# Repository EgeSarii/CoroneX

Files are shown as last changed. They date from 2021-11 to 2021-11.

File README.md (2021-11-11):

# CoroneX User Guide

This is CoroneX safety system which includes everything you wanted for your health.

<div align="center">
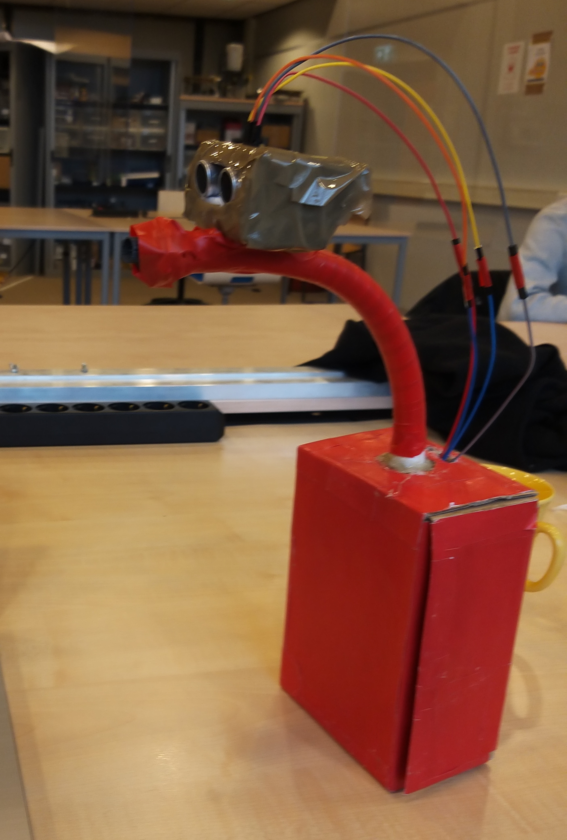
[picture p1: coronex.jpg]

<p>Our pretty CoroneX-bot/boy</p>
</div>

## Navigation Bar
* [What is this exactly?](#what-is-this-exactly)
* [Features](#features)
* [How To Initialize CoroneX](#how-to-initialize-coronex)
* [References](#references)
* [Additional Notes](#additional-notes)

## What is this exactly
> More measurement is needed against corona and it should be automatized

CoroneX is a control mechanism which is mostly designed for entrances of commonly used closed spaces.

It maintains the safety by mainly checking temperature and people counting.

In addition to that, CoroneX comes with environmental air quality, humidity and temperature sensors.

Client themselves can choose appropriate lowerbounds and upperbounds for these features. And in outside of these bounds, your security staff will get warned by e-mail system. 

A video to give you an idea about CoroneX: https://youtu.be/DwOEBgt9jCc

## Features
**on Wemos D1 Mini:**
- Wemos SHT30 Humidity and Temperature Shell: https://www.wemos.cc/en/latest/d1_mini_shield/sht30.html
- CCS811 Air Quality Sensor: https://cdn.sparkfun.com/assets/learn_tutorials/1/4/3/CCS811_Datasheet-DS000459.pdf
---
**on Arduino Uno:**
- MLX90614 Infra-red Thermometer: https://www.melexis.com/en/product/mlx90614/digital-plug-play-infrared-thermometer-to-can
- HC-SR04 Distance sensor: http://web.eece.maine.edu/~zhu/book/lab/HC-SR04%20User%20Manual.pdf
---
**on Your Device:**
- Any web camera connected or IP camera (We used Raspberry Camera Module: https://www.raspberrypi.org/documentation/usage/camera/)

## How To Initialize CoroneX
Setup your device: (For us it was Raspberry Pi 4 and preferably a LINUX distro)

- According to your device, you will probably need I2C, GPIO, SerialPort configs. Be ready for much more necessary library and configurations on your system. There was a pile of solved issues for us in 14 weeks that took our noticable effort...
- on your device download Arduino IDE

Now, we set up Arduino Uno first:
- In board manager choose, Arduino Uno configurations.
- Import necessary libraries from library manager in Arduino IDE that is related with mlx-thermometer.ino.
- Connect the cables of MLX and HC-SR04 to Uno properly.
- Connect your Uno to USB port of your device. Upload mlx-thermometer.ino to your Arduino Uno and it's done!

(Optional) Secondly, we set up WEMOS D1 Mini:
- In Arduino IDE's preferences add: https://arduino.esp8266.com/stable/package_esp8266com_index.json
- In board manager choose, WEMOS D1 Mini & R2... configurations
- Import necessary libraries from library manager in Arduino IDE that is related with HealthyRoom.ino.
- Don't forget to change variables ssid to your Wi-Fi's ssid and password to your Wi-Fi's password. Be sure that WEMOS and your device is connected to the same network.
- Connect the cables of CCS811 and SHT30 to WEMOS properly.
- Connect your WEMOS to USB port of your device. Upload HealthyRoom.ino to your WEMOS and it's done!

Now, back to our device:
- Install Python 3.7
- with pip3 install, install requirements you will find in /python_code/People-Counting-in-Real-Time-master/requirements.txt
- Run CoroneX.py via your editor or using bash:
```
	python3 CoroneX.py
```
- Enter all your credentials and submit them! It is pretty straight-forward process(YOUR PROGRAM WILL CRASH IN ILLEGAL CASES, IF YOUR CREDENTIALS ARE WRONG!)
- It will initialize the example testing video, if there are no URLs entered.
- In case of library non-existance raises, we are sorry to be not mentioned it about requirements.txt. 

## References
People tracking and counting mainly implemented by using this repository.
```
	https://github.com/saimj7/People-Counting-in-Real-Time.git
```
You can find his references in his page also in "python_code" folder that contains altered version of his project.

## Additional Notes

- Some sort of files is unnecessary for this project. We couldn't find a time to clean all of them. You can easily distinguish the relatable codes and files from unrelated ones.

[Back to navigation bar](#navigation-bar)

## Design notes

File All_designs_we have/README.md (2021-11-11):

This is the folder of the designs for our mechanical part for measurement box. It contains 3 parts. 
We have designed this and thought we can print it by 3D printer, but its going to be more than 30 hours
so we decided to cancel them. Yet we have uploaded. 
The parts contains the components of design. We have done our current design inspirend by these designs and components.

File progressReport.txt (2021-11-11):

Progress report team1-2 (Ege SARI s1034535 Alperen OZKURT s1037565)

W45 2-8 November 

We have worked on fixing DHT-22, our humidity sensor. 
We have accomplished to fix it but it is unstable so we have decided to work with a 
humidity-temperature sensor shield SHT-30 in order to make progress and SHT-30 works. 
Also we have worked about sending an e-mail to users when the temperature or 
humidity is anormal in the room space and managed it! In conclusion, we have done 
debugging and fixing and also added a new feature about sending an e-mail with related 
to humidity-temperature sensor.

W46 9-15 November

We have worked on creating a web iste for the users as a user interface, where the users
 can change the e-mail address to send or to receieve and also the users can change the 
 intervals for safe limits of temperature and humidity levels. Besides this, we have 
 created an executable file of our python program and merged it with our website so 
 when the executable file is on run, both Arduino (temperature and humidity) and 
 Python(CO2 levels and amount of volatile organic compounds) will work. We have done 
 that but since Raspberry pi 4 is a bit slow, we couldn't manage to run that. In finally, 
 we have also started to work on a cover which fits on the raspberry pi and cables so that 
 our project would look nice.

W47 16-22 November

We have finished our 3D project for cover but it didn't worked because we have designed it in milimeters. So for that we failed, we will work on that next week. Also we have improved the graphical user interface for the inputs, which looks more stylish.

W48 23-29 November

We have worked on the cover for our components and we have managed it, the last job for this is to decorate it with coloured papers or paint. Also we have nearly completed our interface for users.

W49 30 November-6 December

We have completed the interface for users and worked on debugging for some small mistakes and problems. Also we have worked on the intervals for optimal temperature values.

W50 7-13 December

We have completed most parts of the project. We have managed to connect all components together and connected it with user interfaces, warning e-mail system. Also we have attached a distance sensor in order to check if the user use thermometer in a correct way. Also we have completed a cover for the components. So we are close to the end. Next week we are planning to record a video for demonstration of our project and we will write a proper report and also we are planning to present our project.

W51 14-20 December
We have completed the project! We have also added Url section for IP cameras and also tested our project. It works as wanted. We have recorded some videos and taken some pictures. Also while I was writing this report, we are uploading the project code to here, Gitlab. 
We have completed the project in time and we are very happy about it.

W52 21-27 December

W53 28 December-3 January

W1 4-10 January

w2 11-17 January

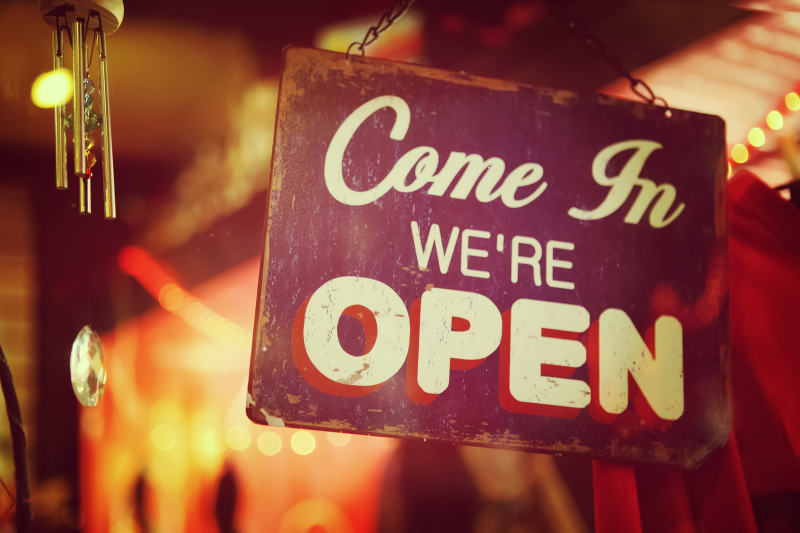
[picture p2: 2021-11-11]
python_code/People-Counting-in-Real-Time-master/download.png

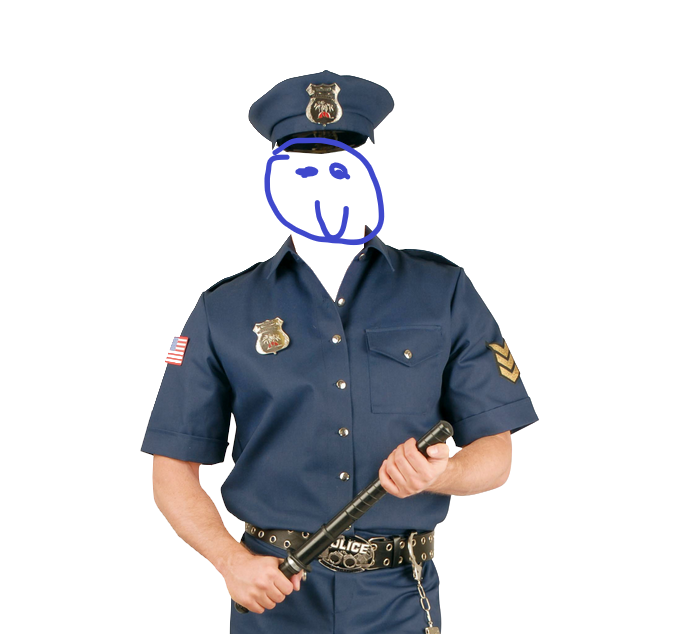
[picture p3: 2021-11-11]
python_code/People-Counting-in-Real-Time-master/REPRES.png

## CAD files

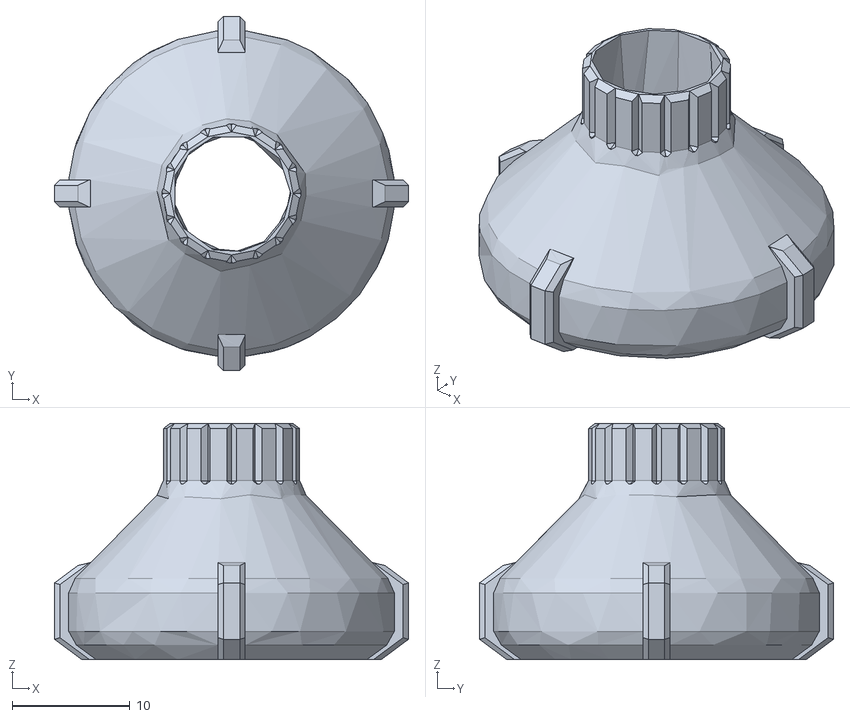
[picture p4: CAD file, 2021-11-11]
All_designs_we have/part1/işte.obj
30.0 x 30.0 x 20.0

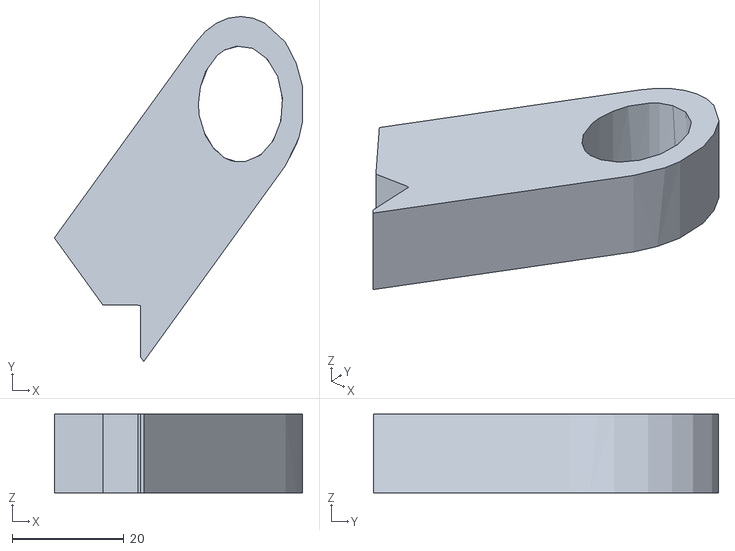
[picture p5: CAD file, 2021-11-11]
All_designs_we have/part2/kankss.obj
44.4 x 61.7 x 14.1

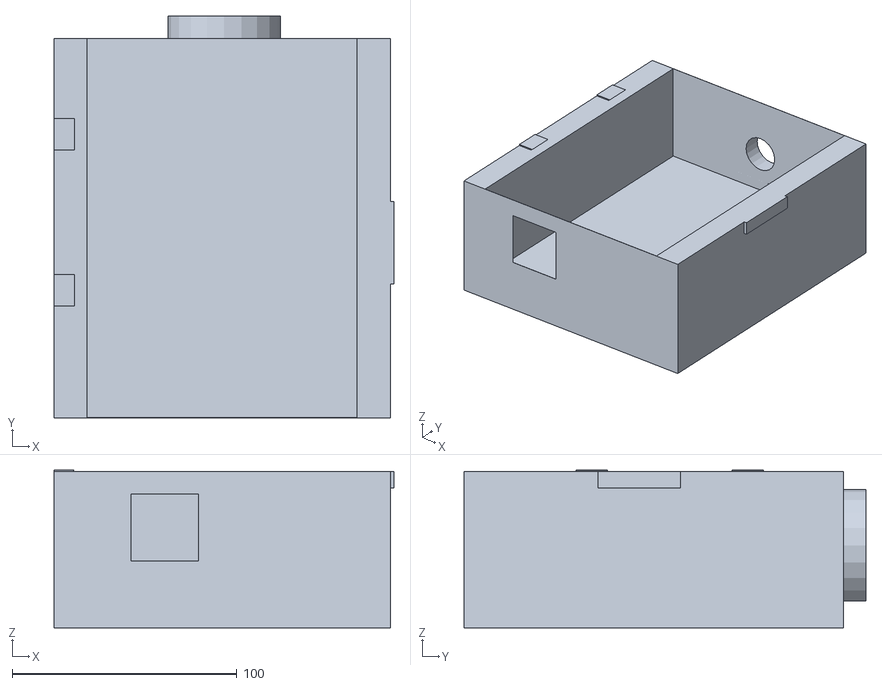
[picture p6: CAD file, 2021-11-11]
All_designs_we have/part3/yürügit.obj
151.4 x 178.8 x 70.3

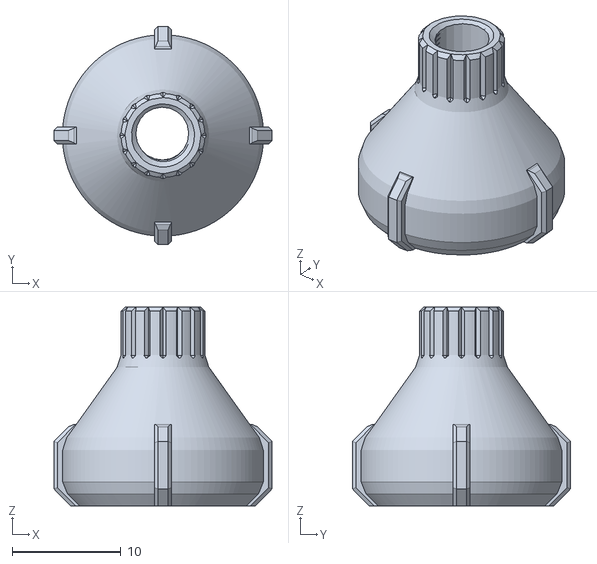
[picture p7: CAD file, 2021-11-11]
The_cap.stl
20.0 x 20.0 x 18.3

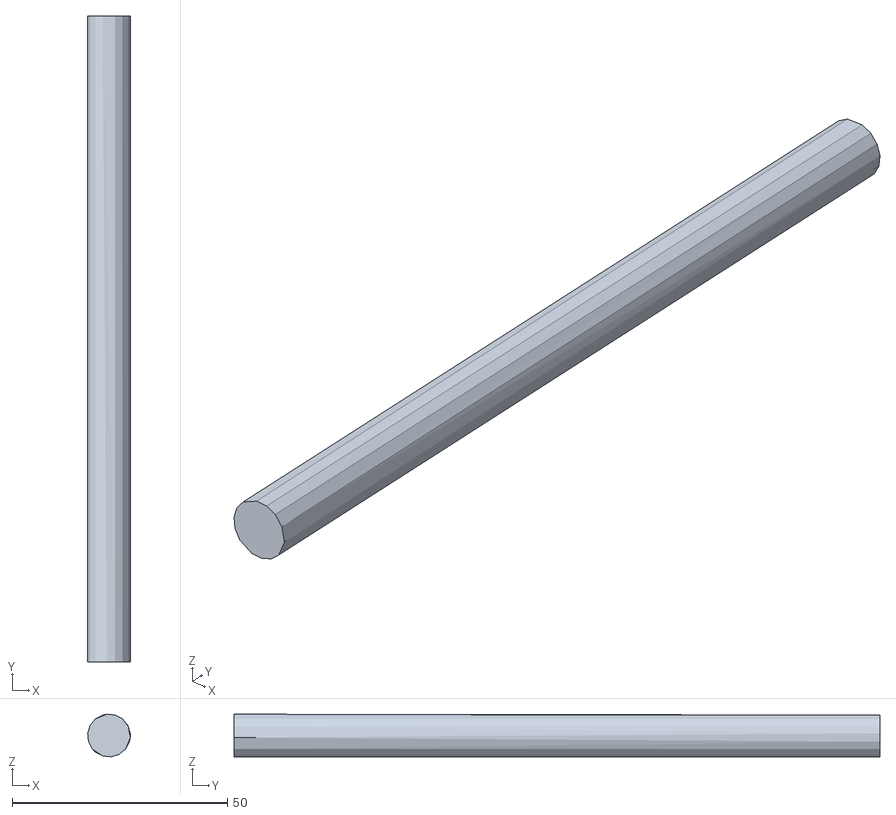
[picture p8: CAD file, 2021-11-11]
All_designs_we have/part1/tövbe.obj
9.91 x 150.0 x 9.90

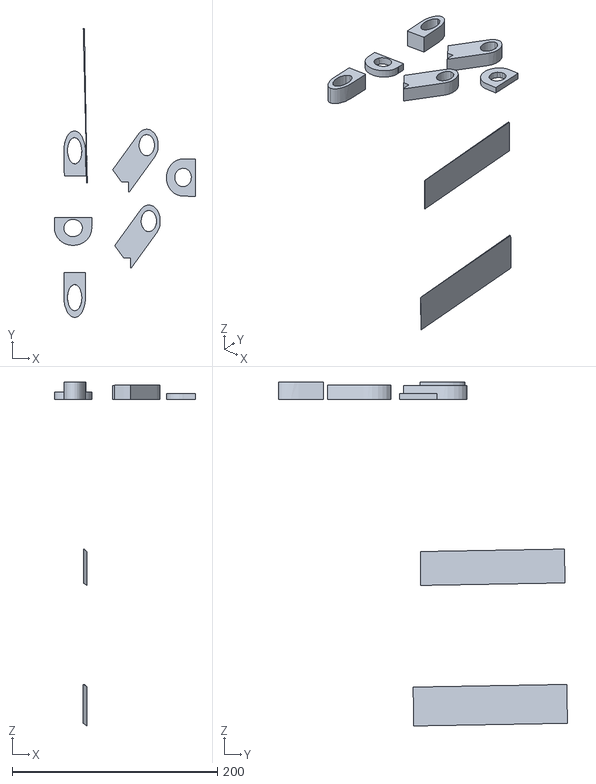
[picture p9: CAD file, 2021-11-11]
All_designs_we have/part2/yeter.obj
137.8 x 281.9 x 335.5

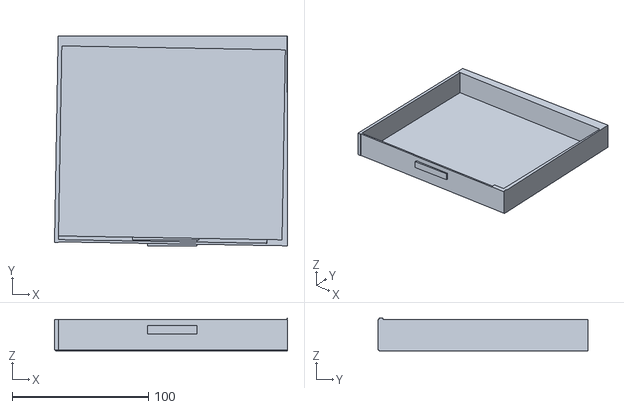
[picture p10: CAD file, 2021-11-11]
All_designs_we have/part3/kafamda.obj
170.8 x 154.0 x 24.0

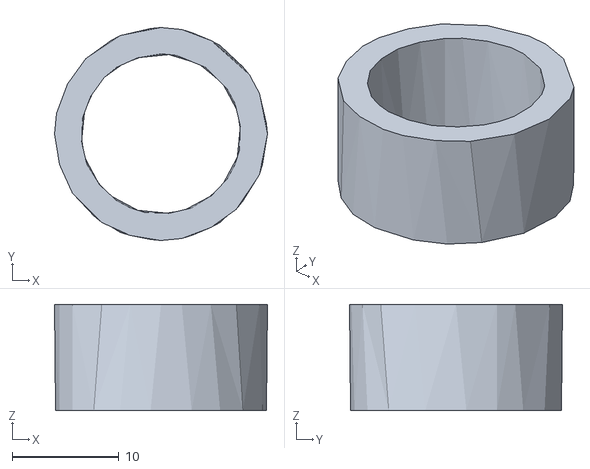
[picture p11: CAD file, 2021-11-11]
All_designs_we have/part1/dnm.obj
20.0 x 20.0 x 10.0

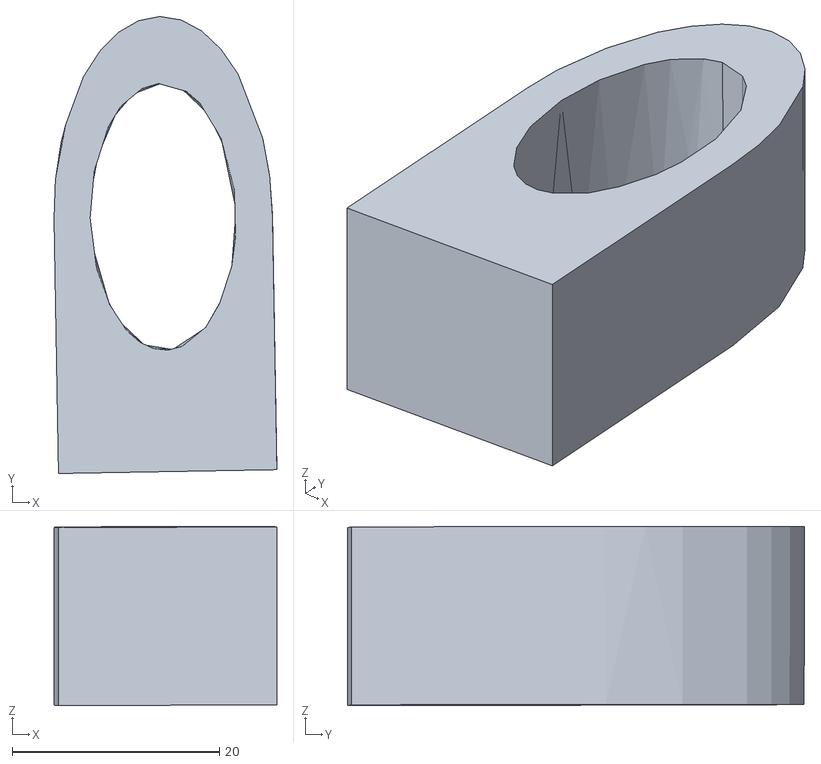
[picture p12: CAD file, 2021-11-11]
All_designs_we have/part2/ohafalan.obj
21.5 x 44.1 x 17.3

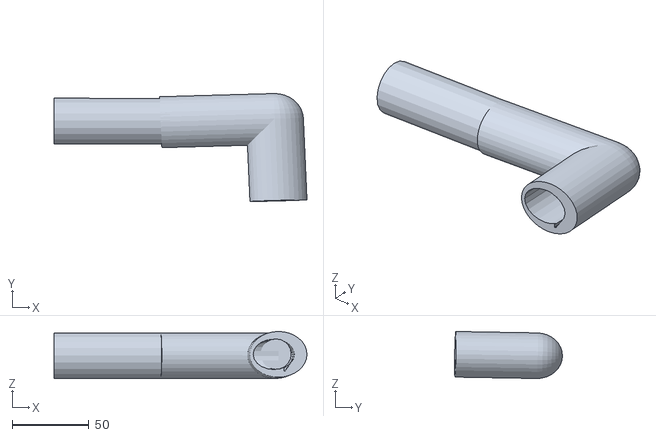
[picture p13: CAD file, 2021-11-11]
All_designs_we have/part1/boru.obj
165.3 x 70.5 x 30.7

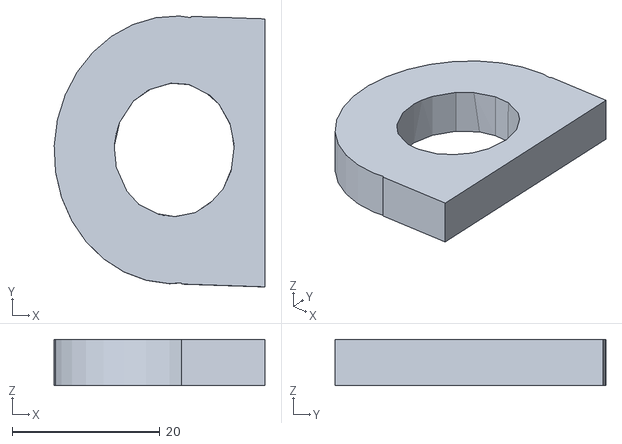
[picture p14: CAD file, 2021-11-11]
All_designs_we have/part2/t12.obj
28.5 x 36.7 x 6.25

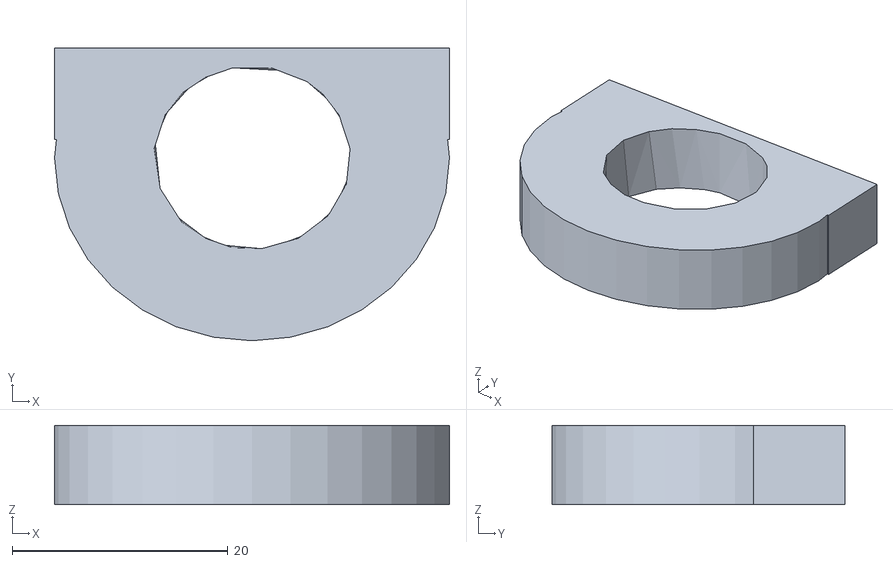
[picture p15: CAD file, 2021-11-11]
All_designs_we have/part2/t2q3w.obj
36.6 x 27.1 x 7.36

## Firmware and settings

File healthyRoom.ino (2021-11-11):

#include <WEMOS_SHT3X.h>
#include <Arduino.h>

#ifdef ESP32
#include <WiFi.h>
#include <AsyncTCP.h>
#else
#include <ESP8266WiFi.h>
#include <ESPAsyncTCP.h>
#endif
#include <ESPAsyncWebServer.h>

#include <unistd.h>
#include <stdlib.h>
#include <iostream>  
#include <string>  
#include <EMailSender.h>
#include <sstream>

#include "Adafruit_CCS811.h"

#define LISTENPORT 80

using namespace std;

//Air Quality Sensor
Adafruit_CCS811 ccs;

//WI-FI Setup of Wemos
const char* ssid = "NDL_24G" ;
const char* password = "RT-AC66U";

//ALL ABOUT WEB-SERVER COMMUNICATION
AsyncWebServer server(LISTENPORT);

void notFound(AsyncWebServerRequest *request) {
  request->send(404, "text/plain", "Not found");
}

const char* PARAM_INPUT_1 = "input1";
const char* PARAM_INPUT_2 = "input2";
const char* PARAM_INPUT_3 = "input3";
const char* PARAM_INPUT_4 = "input4";
const char* PARAM_INPUT_5 = "input5";
const char* PARAM_INPUT_6 = "input6";
const char* PARAM_INPUT_7 = "input7";
const char* PARAM_INPUT_11 = "input11";
const char* PARAM_INPUT_12 = "input12";
const char* PARAM_INPUT_13 = "input13";
const char* PARAM_INPUT_15 = "input15";
const char* PARAM_INPUT_17 = "input17";

//WEB PAGES AS HTML CODES
const char webPage[] PROGMEM= R"rawliteral(<!DOCTYPE html>  <html>   <head>  <meta name="viewport" content="width=device-width, initial-scale=1">  <title> Login Page </title>  <style>   Body {  font-family: Calibri, Helvetica, sans-serif;  background-color: DeepSkyBlue;  } input[type=submit] {   background-color: #FFF;   width: 100%;  color: HotPink;   padding: 15px;   margin: 10px 0px;    border: none;   cursor: pointer;   }   form {    border: 3px solid #f1f1f1;   }   input[type=text], input[type=password] {   width: 100%;   margin: 8px 0;  padding: 12px 20px;   display: inline-block;   border: 2px white;    box-sizing: border-box;   }  button:hover {   opacity: 0.7;   }   .container {   padding: 25px;    background-color: HotPink;  } .imgcontainer {text-align: center;margin: 24px 0 12px 0;}   </style>   </head>    <body>    <center> <h1> Temperature and Humidity Security Protocol </h1> </center> <div class = "imgcontainer"> <img src= "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
void loop() {
  EMailSender emailSend(usermail.c_str(), userpassword.c_str()); //Environmental Humidity and Temperature Postman
  EMailSender emailSend2(usermail2.c_str(), userpassword2.c_str()); //Air Quality Postman


  /*
      MAIL LAYOUT: 
      message.subject <- mail subject
      message.message <- your mail content (add different types carefully with "+=" if it is needed)
      EMailSender::Response resp = emailSend.send(sendToMail.c_str(), message); <- sends your mail to sendToMail person with your favourite postman 
  */
  
  while(true){
  delay(30000);
  //ENVIRONMENTAL FEEDBACKS TO SECURITY
  if(sht30.get()==0){
    Serial.print("Temperature in Celsius : ");
    Serial.println(sht30.cTemp);
    Serial.print("Temperature in Humidity : ");
    Serial.println(sht30.humidity);
    if(sht30.cTemp < lowTemp.toInt())
    {
      message.subject = "LOW TEMPERATURE"; 
      message.message = "Temperature is LOW: ";
      message.message += sht30.cTemp;
      message.message += "! Place need to be keep warmer!!!";
      EMailSender::Response resp = emailSend.send(sendToMail.c_str(), message);
 
      Serial.println("Sending status: ");
      Serial.println(resp.code);
      Serial.println(resp.desc);
      Serial.println(resp.status);
    }
    else if(sht30.cTemp > highTemp.toInt())
    {
      message.subject = "HIGH TEMPERATURE";
      message.message = "Temperature is HIGH: " ;
      message.message += sht30.cTemp ;
      message.message += "! Place need to be keep colder!!!";
      EMailSender::Response resp = emailSend.send(sendToMail.c_str(), message);
 
      Serial.println("Sending status: ");
      Serial.println(resp.code);
      Serial.println(resp.desc);
      Serial.println(resp.status);
    }
   
    if(sht30.humidity < lowHumidity.toInt())
    {
      message.subject = "LOW HUMIDITY";
      message.message = "Humidity is LOW: ";
      message.message += sht30.humidity ;
      message.message += "! Place need to be more humid!!!";
      EMailSender::Response resp = emailSend.send(sendToMail.c_str(), message);
 
      Serial.println("Sending status: ");
      Serial.println(resp.code);
      Serial.println(resp.desc);
      Serial.println(resp.status);
    }
    else if(sht30.humidity > highHumidity.toInt())
    {
      message.subject = "HIGH HUMIDITY";
      message.message = "Humidity is HIGH: ";
      message.message += sht30.humidity;
      message.message += "! Place need to be keep drier!!!";
      EMailSender::Response resp = emailSend.send(sendToMail.c_str(), message);
 
      Serial.println("Sending status: ");
      Serial.println(resp.code);
      Serial.println(resp.desc);
      Serial.println(resp.status);
    }
  }
  else
  {
    Serial.println("Error on SHT!");
  }
  //AIR QUALITY FEEDBACKS TO SECURITY
  if(ccs.available()){
    if(!ccs.readData()){
    Serial.print("CO2 level: ");
    Serial.println(ccs.geteCO2());
    Serial.print("VOC level: ");
    Serial.println(ccs.getTVOC());
    if(ccs.geteCO2() > highCO2.toInt())
    {
      message.subject = "HIGH CO2 LEVEL";
      message.message = "CO2 is HIGH: " ;
      message.message += ccs.geteCO2();
      message.message += "! Place need to be keep conditioned, more oxygen needed!!!";
      EMailSender::Response resp = emailSend2.send(sendToMail2.c_str(), message);
 
      Serial.println("Sending status: ");
      Serial.println(resp.code);
      Serial.println(resp.desc);
      Serial.println(resp.status);
    }
  
    if(ccs.getTVOC() > highVOC.toInt())
    {
      message.subject = "HIGH VOC";
      message.message = "VOC is HIGH: ";
      message.message += ccs.getTVOC();
      message.message += "! Place need to be conditioned VOC is dangerous!!!";
      EMailSender::Response resp = emailSend2.send(sendToMail2.c_str(), message);
 
      Serial.println("Sending status: ");
      Serial.println(resp.code);
      Serial.println(resp.desc);
      Serial.println(resp.status);
    }}
    else{
      Serial.println("ERROR");
      while(1);
    }
    
  }
  delay(30000);}
 
}

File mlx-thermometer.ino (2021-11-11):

#include <Wire.h>
#include <Adafruit_MLX90614.h>

/*
  Related components: HC-SR04 distance sensor
                      MLX90614 Infra-red thermometer
*/

//Distance sensor pins
#define echoPin 2 // attach pin D2 Arduino to pin Echo of HC-SR04
#define trigPin 3 //attach pin D3 Arduino to pin Trig of HC-SR04


//defines variables
Adafruit_MLX90614 mlx = Adafruit_MLX90614();
long duration; // variable for the duration of sound wave travel
int distance; // variable for the distance measurement

//Very straight-forward process:
//Serial-port 9600 communication with Raspberry Pi about distance cross-checked human temperature feedback.

void setup() {
  Serial.begin(9600);
  pinMode(trigPin, OUTPUT); // Sets the trigPin as an OUTPUT for HC-SR04
  pinMode(echoPin, INPUT); // Sets the echoPin as an INPUT for HC-SR04
  mlx.begin();  //starts infrared thermometer
}

void loop() {
  
  // Clears the trigPin condition
  digitalWrite(trigPin, LOW);
  delayMicroseconds(2);
  // Sets the trigPin HIGH (ACTIVE) for 10 microseconds
  digitalWrite(trigPin, HIGH);
  delayMicroseconds(10);
  digitalWrite(trigPin, LOW);
  // Reads the echoPin, returns the sound wave travel time in microseconds
  duration = pulseIn(echoPin, HIGH);
  // Calculating the distance
  distance = duration * 0.034 / 2; // Speed of sound wave divided by 2 (go and back)
  //This distance value represents distance between object(person) and the distance sensor in terms of centimeter. 
  //We only send the information of human temperature if the person is in range, otherwise 0

  if(distance <=6){ 
    Serial.println(mlx.readObjectTempC()); 
  }
  else{
    Serial.println(0);
  }
  delay(500);
}
